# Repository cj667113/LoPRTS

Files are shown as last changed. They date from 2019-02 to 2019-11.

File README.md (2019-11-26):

# LoPRTS V1.3 

Low Power Remote Temperature Sensor
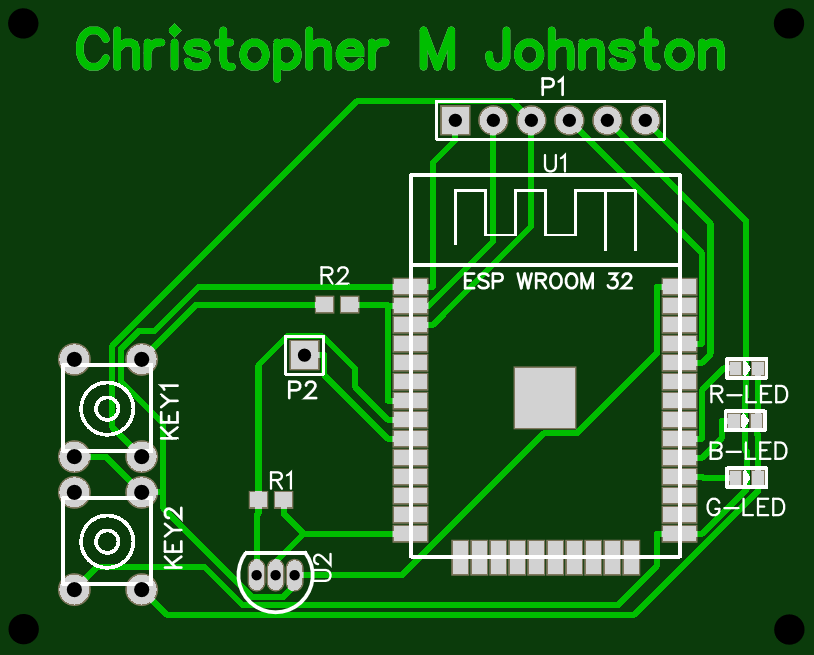
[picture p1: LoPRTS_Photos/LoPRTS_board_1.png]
LoPRT Board


This project was designed with the ESP32-WROOM module with Micropython. Essentially, this project allows for Low Powered Remote Temperature Sensor to be used in conjection with PRTG. By installing an HTTP Push Device in PRTG, you will be allowed to point and push data to the sensor. This will allow us to put the ESP32 into deep sleep to conserve battery power, and allow the device to wake up and report a messurement without worrying about IP addressing and reduce the amount of time the ESP32 has to stay awake.

Included in this project is the custom PCB boards I designed, temperature.py which is the code used to report the measurements, and the STL files for the case.

# LoPRTS V1.3-Current Changes
<b>Hardware:</b>
1. None

<b>Software:</b>
1. MQTT subversion. Included Simple Github OTA Updater (https://github.com/cj667113/simple_github_ota_updater) that will monitor the repository and install new software after each hard-reset. MQTT Version will use JSON Payload to send Datetime ,Temperature and Voltage.

# Micropython
http://micropython.org/download

I am using micropython version esp32-20190619-v1.11-49-g34c04d231.bin.

I used Esptools.py to connect to the board to erase the board and flash the firmware to it. Hold Key 2 down while pressing Key 1 to enter download mode.

I used Ampy to put the temperature.py code as boot.py on the board. After flashing the board, press Key 1 to reset the board, before uploading with Ampy.

# Wake-up Control Pin
I included P2 as a Touch Pin to force wake the micropython controller. In the designs of my case I used a small piece of copper plate that I had left over from raspberry pi heat sinks to fit the case. Similiar to the link below:

(https://www.amazon.com/Lanpu-Raspberry-Heatsink-Aluminum-cooling/dp/B079K43ZTZ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)

# Power On/Off & Deepsleep
Note that the LoPRTS system works as soon as you attach a power supply, there is no off function, rather there is only deepsleep. That means there has to be reliable WiFi connection or else the system will just search for a WiFi point. I notice that this might be an issue so I am going to update the code to go to deepsleep after I have time. 

# Battery Life
For the PBC board, you can use a linear voltage regulator with the trade off of effeciency to the batteries. I ran the boards on 4-D batteries in parallel and in series to get a battery of 26,000 mah at 3V. I concluded that if the ESP32 took 4 seconds to get through the code and report the data and then we placed the board in deep sleep for 15 minutes then:

250ma (peak current)*(4/(900+4))
<p>250ma*(.004424)=1.106ma
<p>1.106+1 (deep sleep current)=2.106ma
<p>26,000/2.106=12,345 hours
<p>12,345 * 70% (efficency)= 8,642 hours or 360 days on batteries

**Note that Energizer rates their D-Batteries at 20,000mah @ 25ma typical draw, applying this, then the battery life may be even longer than 360 days. **

# MQTT Version

You will need to also upload a setup.txt file to the ESP32. Please look at setup_example.txt for the format. This file should take care of all the information that your unique setup will require.

# PRTG Version

Once you download and setup PRTG, you can install a HTTP Push Data Sensor, so that the ESP32 can send Temperature and Voltage statuses to PRTG. The following is what my graph looks like:

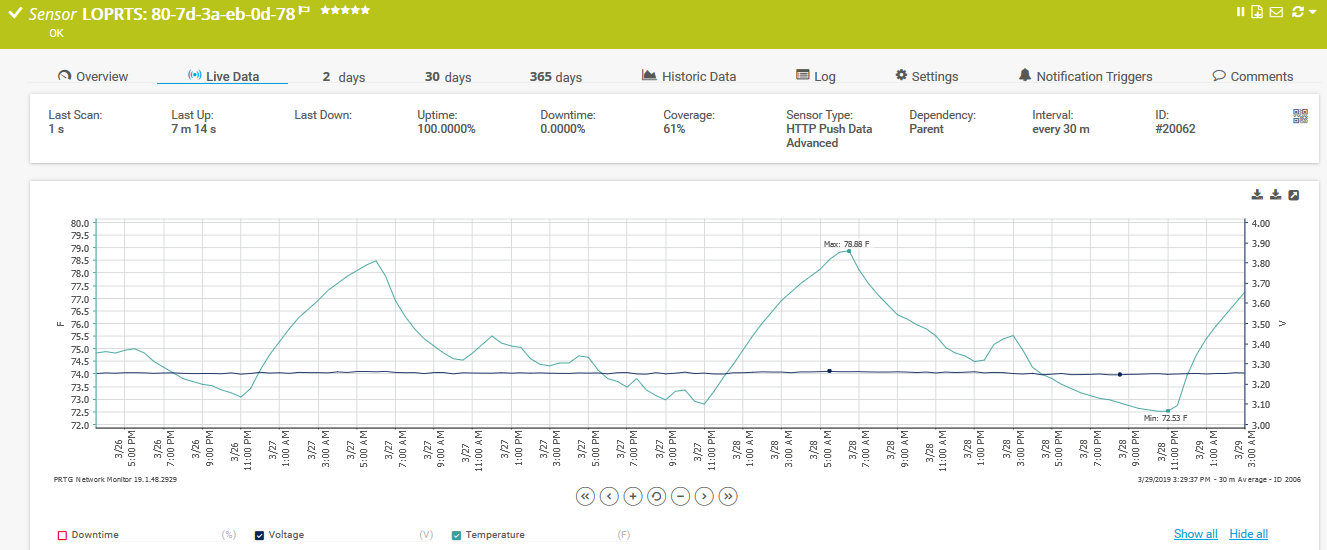
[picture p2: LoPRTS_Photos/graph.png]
PRTG_Integration


# Fully Assembled
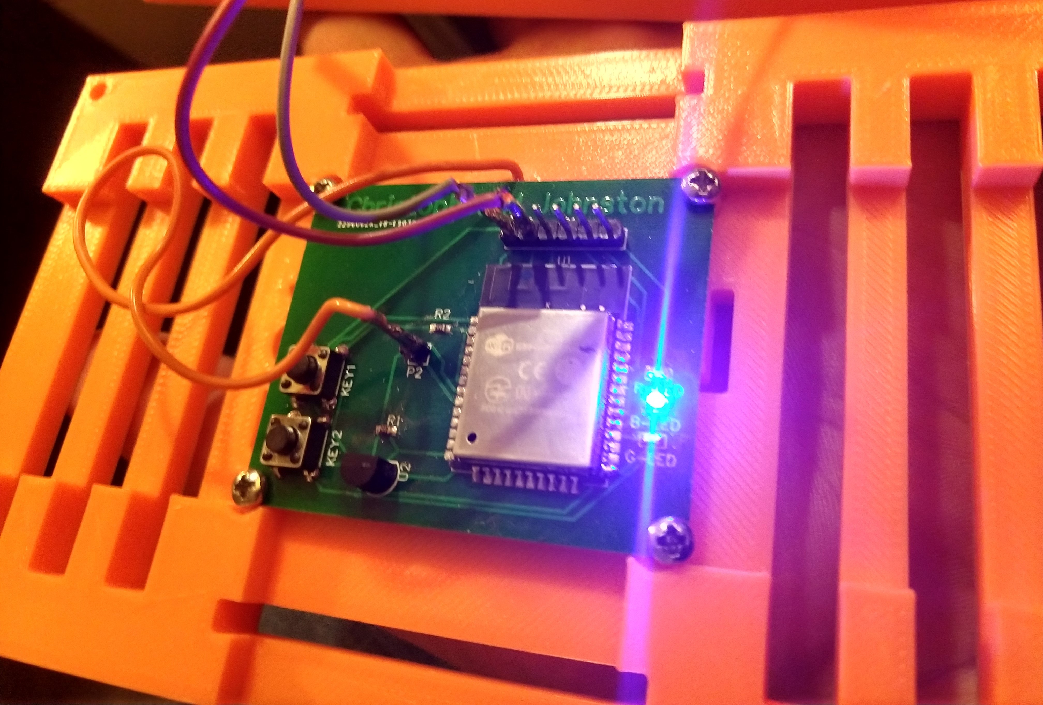
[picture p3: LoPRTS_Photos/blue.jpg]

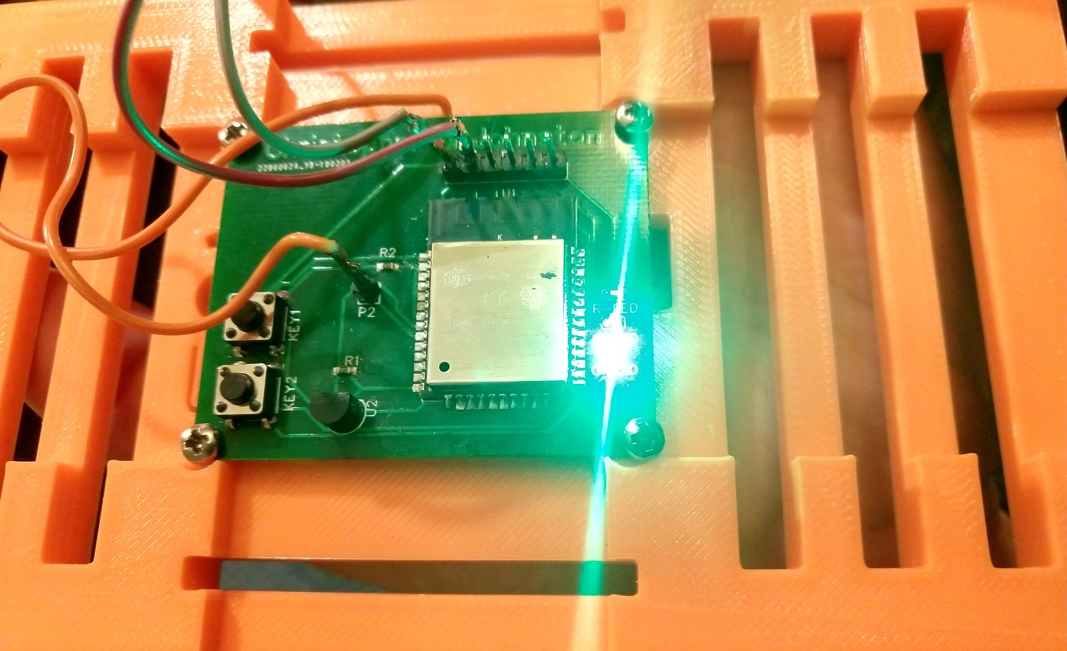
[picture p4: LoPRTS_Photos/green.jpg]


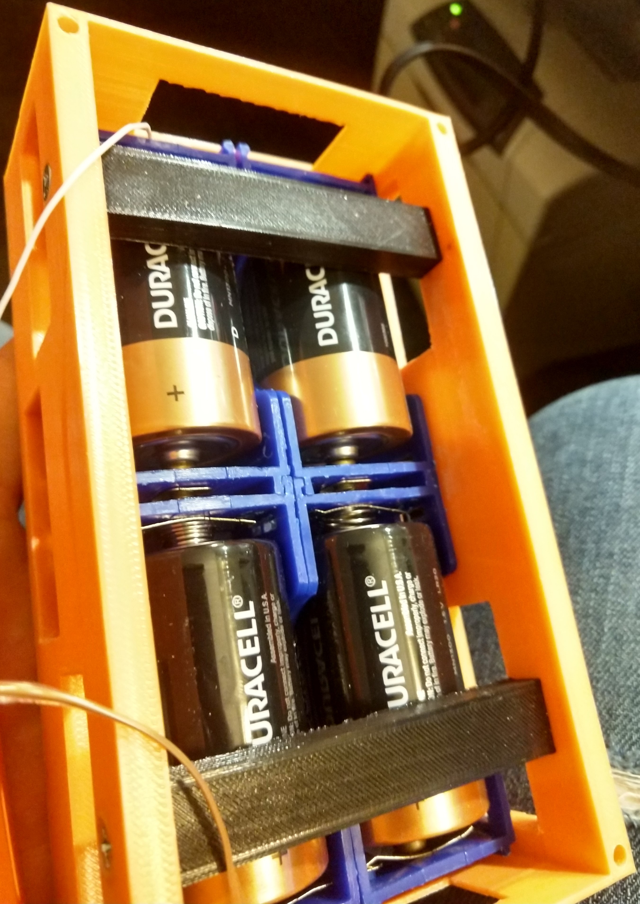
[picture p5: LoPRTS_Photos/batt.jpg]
LoPRTS Total


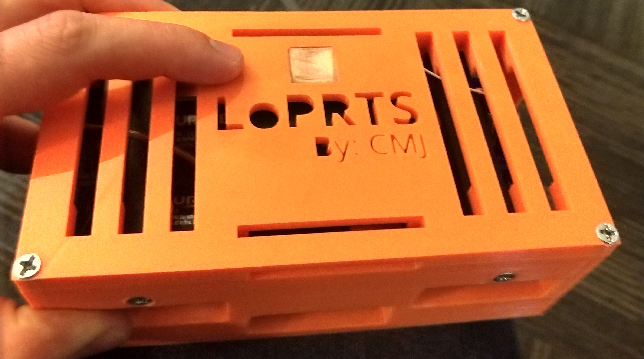
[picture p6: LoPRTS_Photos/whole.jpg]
LoPRTS_Full


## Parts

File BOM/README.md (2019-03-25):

# Bill of Materials as Found on Amazon
Battery Holder: https://www.amazon.com/gp/product/B01LVUT6D5/ref=ppx_yo_dt_b_asin_title_o03_s00?ie=UTF8&psc=1

Temperature Sensor: https://www.amazon.com/gp/product/B01IVMJ1L2/ref=ppx_yo_dt_b_asin_title_o03_s01?ie=UTF8&psc=1

ESP32: https://www.amazon.com/gp/product/B07BDM15HY/ref=ppx_yo_dt_b_asin_title_o05_s01?ie=UTF8&psc=1

Buttons: https://www.amazon.com/gp/product/B06Y56KPBS/ref=ppx_yo_dt_b_asin_title_o03_s00?ie=UTF8&psc=1

USB-Serial Programer: https://www.amazon.com/gp/product/B07G2256WK/ref=ppx_yo_dt_b_asin_title_o04_s00?ie=UTF8&psc=1

LEDs: https://www.amazon.com/gp/product/B01CUGA380/ref=ppx_yo_dt_b_asin_title_o05_s00?ie=UTF8&psc=1

Resistors: https://www.amazon.com/gp/product/B00VXTANM2/ref=ppx_yo_dt_b_asin_title_o01_s00?ie=UTF8&psc=1

Male-Female Jumper Wires: https://www.amazon.com/gp/product/B01L5ULRUA/ref=ppx_yo_dt_b_asin_title_o03_s00?ie=UTF8&psc=1

Header Pins: https://www.amazon.com/gp/product/B06Y4S6G29/ref=ppx_yo_dt_b_asin_title_o04_s00?ie=UTF8&psc=1

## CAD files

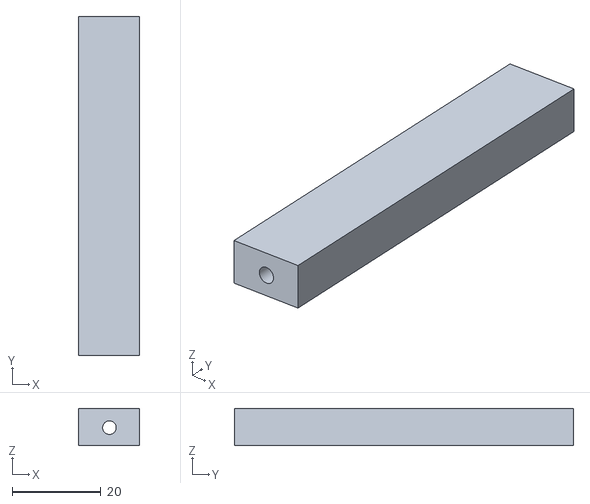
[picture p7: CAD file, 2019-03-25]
LoPRTS_stl/LoPRTS_Mount.stl
13.8 x 76.2 x 8.35

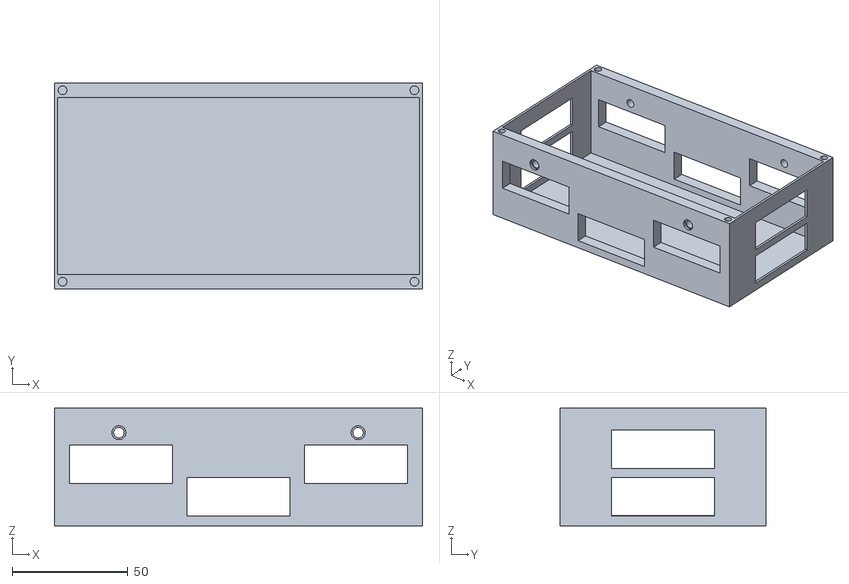
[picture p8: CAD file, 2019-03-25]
LoPRTS_stl/LoPRTS_Base_Plate.stl
158.8 x 88.9 x 50.8

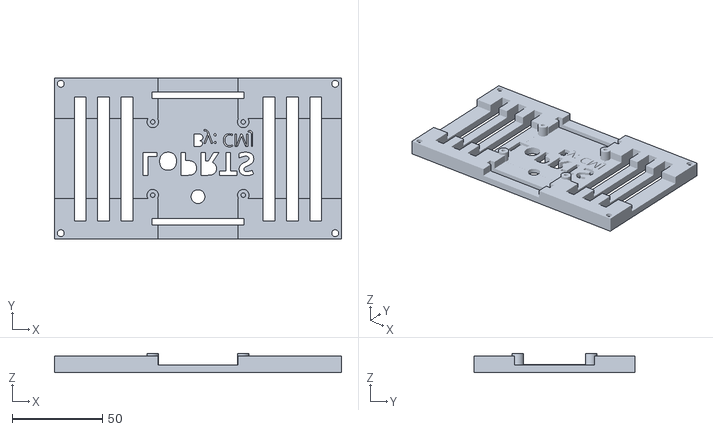
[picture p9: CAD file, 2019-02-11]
LoPRTS_stl/LoPRTS_Face_Plate.stl
158.8 x 88.9 x 10.7

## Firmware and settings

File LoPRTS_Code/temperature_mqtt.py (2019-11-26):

import machine
import os
import uos
import time
import onewire
import ds18x20
import network
import esp
import esp32
import ubinascii
import ntptime
import usgota
import gc
import ujson
from umqtt_simple import MQTTClient
machine.freq(80000000)
esp.osdebug(None)
touch=machine.TouchPad(machine.Pin(33))
touch.config(1000)
esp32.wake_on_touch(True)
adc_pin = machine.Pin(35)
adc=machine.ADC(adc_pin)
adc.atten(adc.ATTN_11DB)
print(os.uname())
client_id = ubinascii.hexlify(machine.unique_id())
def setup():
    global SSID
    global SSID_password
    global mqtt_server
    global user
    global password
    try:
        uos.stat('setup.txt')
        print('Loading Setup')
        config=open('setup.txt','r')
        config=config.readline()
        config=config.split('|')
        SSID=config[0]
        SSID_password=config[1]
        mqtt_server=config[2]
        user=config[3]
        password=config[4]
    except:
        print('Error: Upload setup.txt')
def time_get():
    ntptime.settime()
def voltage_read():
    global vval
    vval=adc.read()
    vval=vval*(3.3/4095)
    print(vval)
def wlan():
    voltage_read()
    global sta_if
    sta_if=network.WLAN(network.STA_IF)
    sta_if.active(True)
    sta_if.connect(SSID,SSID_password)
def connect_and_subscribe(topic,data):
    c = MQTTClient(client_id, mqtt_server,user=user,password=password)
    c.connect()
    c.publish(topic, data)
    c.disconnect()
setup()
try:
    if machine.reset_cause() == machine.DEEPSLEEP_RESET:
        print("Woke From Deepsleep")
        pass
    elif machine.reset_cause()==machine.WDT_RESET:
        print("Watch Dog Time Expired")
        pass
    else:
        wlan()
        while True:
                if sta_if.isconnected()==True:
                    timer=machine.Timer(-1)
                    timer.init(period=60000, mode=machine.Timer.PERIODIC, callback=lambda t:machine.deepsleep(900000))
                    mac=ubinascii.hexlify(network.WLAN().config('mac'),':').decode()
                    mac=mac.replace(':','-')
                    ip=sta_if.ifconfig()
                    print(ip)
                    try:
                        gc.collect()
                        time_get()
                        time.sleep_ms(30)
                    except:
                        print("Time Calibration Error")
                        pass
                    try:
                        gc.collect()
                        usgota.update("https://api.github.com/repos/cj667113/LoPRTS/commits?path=LoPRTS_Code/compiled/temperature_mqtt.mpy")
                        time.sleep_ms(30)
                        break
                    except:
                        print("Update Error")
                        pass
        machine.deepsleep(30)
    timer=machine.Timer(-1)
    timer.init(period=30000, mode=machine.Timer.PERIODIC, callback=lambda t:machine.deepsleep(900000))
    rtc=machine.RTC()
    temp_power = machine.Pin(32,machine.Pin.OUT)
    temp_power.value(1)
    rled=machine.Pin(18,machine.Pin.OUT)
    bled=machine.Pin(5,machine.Pin.OUT)
    bled.value(1)
    gled=machine.Pin(17,machine.Pin.OUT)
    temp_data = machine.Pin(12)
    ds = ds18x20.DS18X20(onewire.OneWire(temp_data))
    roms = ds.scan()
    print(roms)
    temperature = 0
    wlan()
    while True:
            if sta_if.isconnected()==True:
                try:
                    mac=ubinascii.hexlify(network.WLAN().config('mac'),':').decode()
                    mac=mac.replace(':','-')
                    ip=sta_if.ifconfig()
                    print(ip)
                    gled.value(1)
                    bled.value(0)
                    ds.convert_temp()
                    time.sleep_ms(750)
                    gled.value(0)
                    print(rtc.datetime())
                    for rom in roms:
                        temperature=((float((ds.read_temp(rom))*(1.8))+32)-2)
                    voltage_read()
                    temperature=str(temperature)
                    vval=str(vval)
                    topic=(mac)
                    topic.encode()
                    now = time.time()
                    year, month, day, hour, minute, second, ms, dayinyear = time.localtime(now)
                    DateTime=str(str(year)+','+str(month)+','+str(day)+','+str(hour)+','+str(minute)+','+str(second))
                    print(DateTime)
                    data = {"DateTime":DateTime,"Temperature":temperature,"Voltage":vval}
                    data=ujson.dumps(data)
                    print(topic)
                    print(data)
                    connect_and_subscribe(topic,data)
                    time.sleep_ms(30)
                    break
                except:
                    pass
    rled.value(1)
    time.sleep_ms(30)
    temp_power.value(0)
    machine.deepsleep(900000)
except:
    machine.deepsleep(900000)
